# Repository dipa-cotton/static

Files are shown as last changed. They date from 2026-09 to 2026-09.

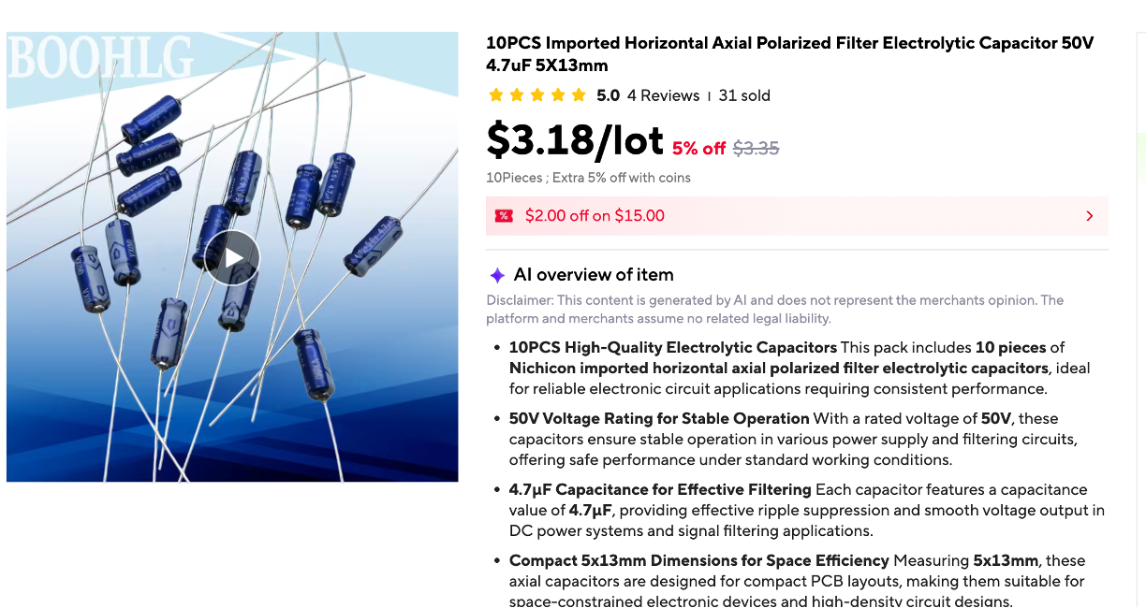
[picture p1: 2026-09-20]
production/cart image files/cart2.png

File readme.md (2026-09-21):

# static
custom FM Radio, with a SX1278 for LoRA capabilities!

## project overview
this FM radio contains a RDA5807, TDA2822, an infrared sensor, and a SX1278. these are the main components, and along with a 0.96 inch OLED display, a microSD card module, and more, this project is versatile and can both play audio as well as function as an FM radio, along with LORA capabilities.

## pictures
Screenshot 2026-09-20 at 2 40 43 PM
Screenshot 2026-09-21 at 4 08 50 PM
Screenshot 2026-09-21 at 4 09 12 PM
There was no CAD Case built for this project, so the case can be built later on once the antenna and potentiometer + button placement can be visualized. (I haven't decided on the button placement for this project yet, so I don't want to constrain placement just yet. Once it is assembled, a case will be built.)

## BOM Overview
- 3 10K ohm resistor
- 1 100 ohm resistor
- 5 polarized capacitors
- 1 4.7 µF decoupling capacitor
- 3 100nF capacitors
- 1 10nF capacitor
- 2 10pf capacitors
- 1 PJ-3200
- 1 0.96in OLED Display
- 1 MicroSD Card Module
- 2 speakers
- 2 potentiometers
- 4 push buttons
- 1 XIAO rp2040 microcontroller
- 1 RDA5807
- 1 TDA2822
- 1 TSOP38238
- 1 SX1278
- 1 32 MHz Crystal
### Overall cost: (including shipping and PCB) is $58

a more detailed list can be found in BOM.csv :)

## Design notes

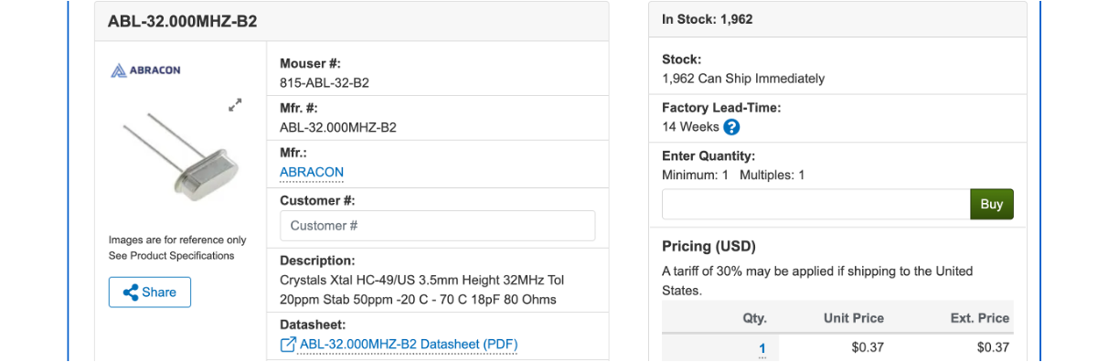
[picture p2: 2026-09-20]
production/cart image files/cart6.png

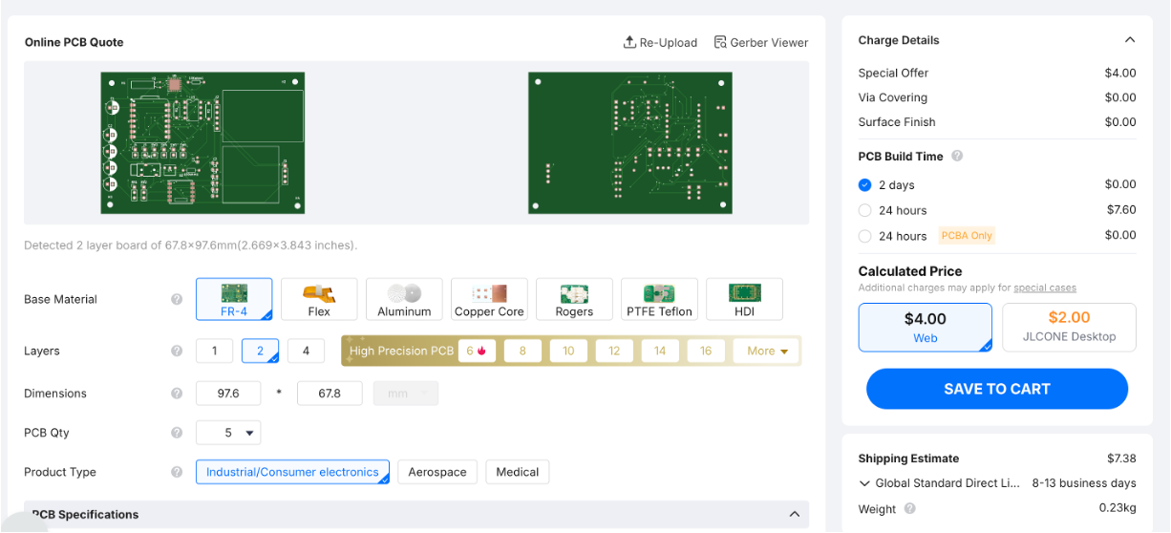
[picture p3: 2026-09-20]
production/cart image files/cart7.png

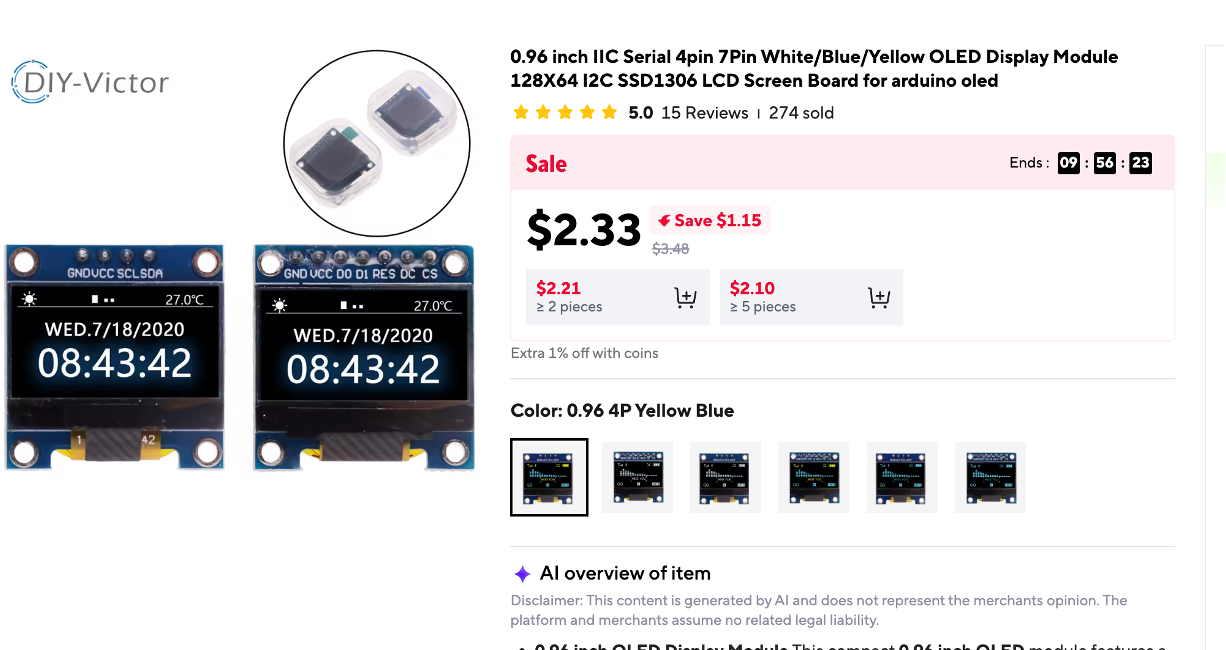
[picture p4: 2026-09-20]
production/cart image files/cart4.png

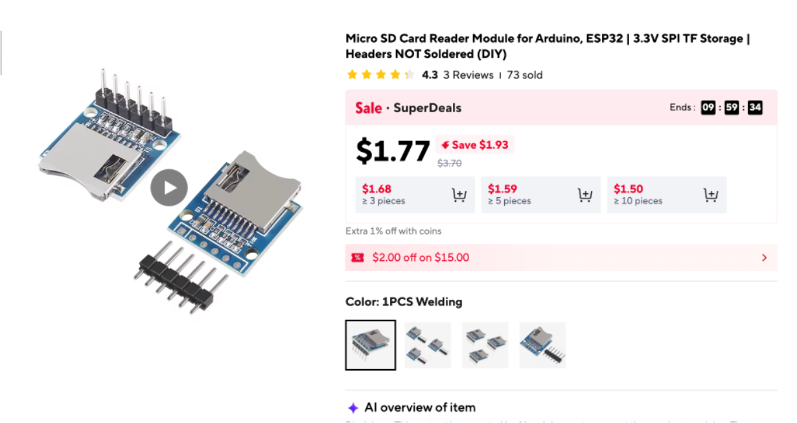
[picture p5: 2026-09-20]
production/cart image files/cart1.png

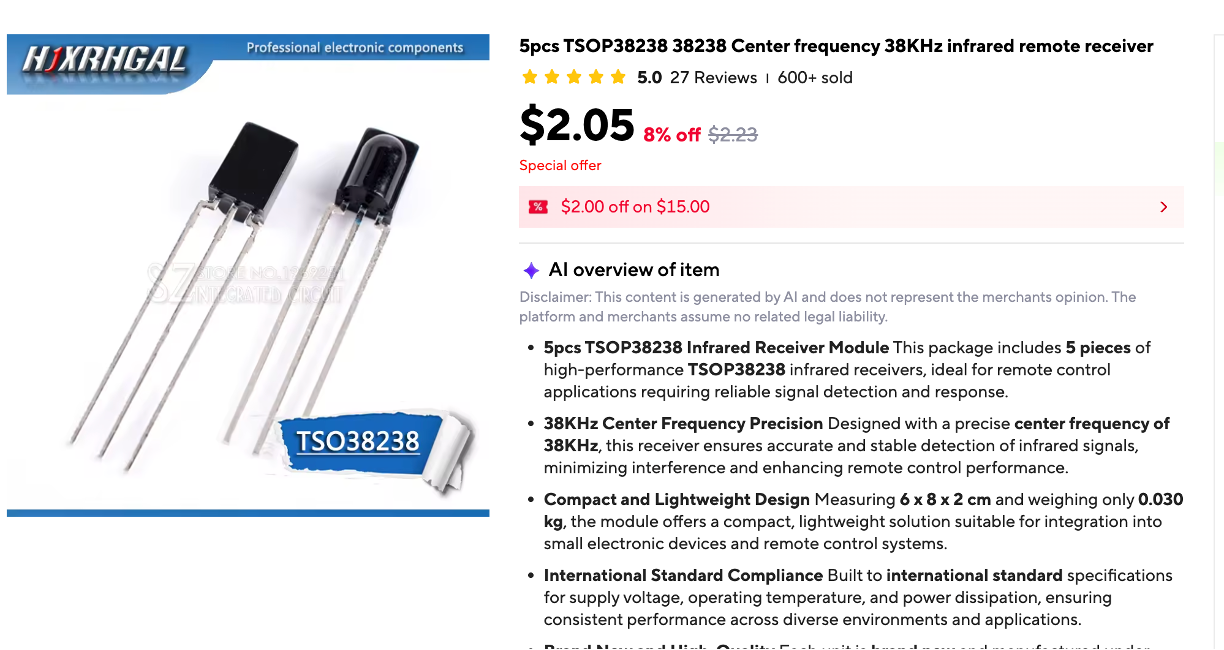
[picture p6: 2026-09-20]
production/cart image files/cart3.png

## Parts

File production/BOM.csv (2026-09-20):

Reference | Qty | Value | DNP | Footprint | Datasheet | Links to buy | Retailer | Cost (dollars)
10Kohm1,100ohm1 | 2 | R |  | Resistor_THT:R_Axial_DIN0204_L3.6mm_D1.6mm_P7.62mm_Horizontal |  | Owned | Owned | 0
C1,C2,C3,C4,C5 | 5 | C_Polarized |  | Capacitor_THT:CP_Radial_D6.3mm_P2.50mm |  | https://www.aliexpress.us/item/3256810508693915.html?curPageLogUid=OJ7CYfMdVWOt | Aliexpress | 4
C6 | 1 | 4.7µF |  | Resistor_THT:R_Axial_DIN0204_L3.6mm_D1.6mm_P1.90mm_Vertical |  | Owned | Owned | 0
C7,C8,C9 | 3 | 100nF |  | Resistor_THT:R_Axial_DIN0204_L3.6mm_D1.6mm_P1.90mm_Vertical |  | Owned | Owned | 0
C10 | 1 | 10nF |  | Resistor_THT:R_Axial_DIN0204_L3.6mm_D1.6mm_P1.90mm_Vertical |  | Owned | Owned | 0
C11,C12 | 2 | 10pf |  | Resistor_THT:R_Axial_DIN0204_L3.6mm_D1.6mm_P1.90mm_Vertical |  | Owned | Owned | 0
CN1 | 1 | PJ-3200 |  | static:AUDIO-TH_PJ-3200 | https://www.lcsc.com/datasheet/C2689690.pdf | included in kit | included in kit | 0
J1 | 1 | 0.96in OLED Display |  | Connector_PinHeader_2.54mm:PinHeader_1x04_P2.54mm_Vertical |  | https://www.aliexpress.us/item/3256806022799299.html?curPageLogUid=FwapZcyoFvRJ | Aliexpress | 3
J2 | 1 | MicroSD Card Module |  | Connector_PinHeader_2.54mm:PinHeader_1x06_P2.54mm_Vertical |  | https://www.aliexpress.us/item/2251832601364265.html?curPageLogUid=IZeHAfpDRn8G | Aliexpress | 2
J4 | 1 | Speaker 1 |  | Connector_PinHeader_2.54mm:PinHeader_1x02_P2.54mm_Vertical |  | included in kit | included in kit | 0
J5 | 1 | Speaker 2 |  | Connector_PinHeader_2.54mm:PinHeader_1x02_P2.54mm_Vertical |  | included in kit | included in kit | 0
R1,R2 | 2 | 10K |  | Resistor_THT:R_Axial_DIN0207_L6.3mm_D2.5mm_P7.62mm_Horizontal |  | Owned | Owned | 0
RV1,RV2 | 2 | R_Potentiometer |  | Connector_PinHeader_2.54mm:PinHeader_1x03_P2.54mm_Vertical |  | included in kit | included in kit | 0
SW3,SW4,SW5,SW6 | 4 | SW_Push |  | Connector_PinHeader_2.54mm:PinHeader_1x02_P2.54mm_Vertical |  | Owned | Owned | 0
U1 | 1 | XIAO-RP2040-DIP |  | static:XIAO-RP2040-DIP |  | included in kit | included in kit | 0
U2 | 1 | RDA5807MRRD-102V2.0 |  | static:RDA5807 | https://www.lcsc.com/datasheet/C9900205627.pdf | included in kit | included in kit | 0
U3 | 1 | TDA2822NBD |  | Package_DIP:DIP-8_W7.62mm | https://www.lcsc.com/datasheet/C51927337.pdf | included in kit | included in kit | 0
U4 | 1 | TSOP38238 |  | ir sensor:TSOP382 | https://www.vishay.com/doc?82491 | https://www.aliexpress.us/item/2251832763007870.html?curPageLogUid=QRFDtZ5iDDtf | Aliexpress | 5
U5 | 1 | SX1278 |  | Package_DFN_QFN:QFN-28-1EP_6x6mm_P0.65mm_EP4.8x4.8mm | https://semtech.my.salesforce.com/sfc/p/ | https://www.digikey.com/en/products/detail/semtech-corporation/SX1278IMLTRT/5226772?gclsrc=aw.ds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 | Digikey | 8
Y2 | 1 | 32 MHz Crystal |  | Crystal:Crystal_AT310_D3.0mm_L10.0mm_Horizontal |  | https://www.mouser.com/en/ProductDetail/ABRACON/ABL-32000MHZ-B2?qs=zLkLEWnxMJxB%252Bk6YRBW6NQ%3D%3D&mgh=1 | Mouser | 1
PCB | 5 |  |  |  |  |  | JLCPCB | 4
 |  |  |  |  |  |  | Shipping | 8 | JLCPCB
 |  |  |  |  |  |  |  | 7 | Aliexpress
 |  |  |  |  |  |  |  | 8 | Digikey
 |  |  |  |  |  |  |  | 8 | Mouser
 |  |  |  |  |  |  | Total Cost: | 58

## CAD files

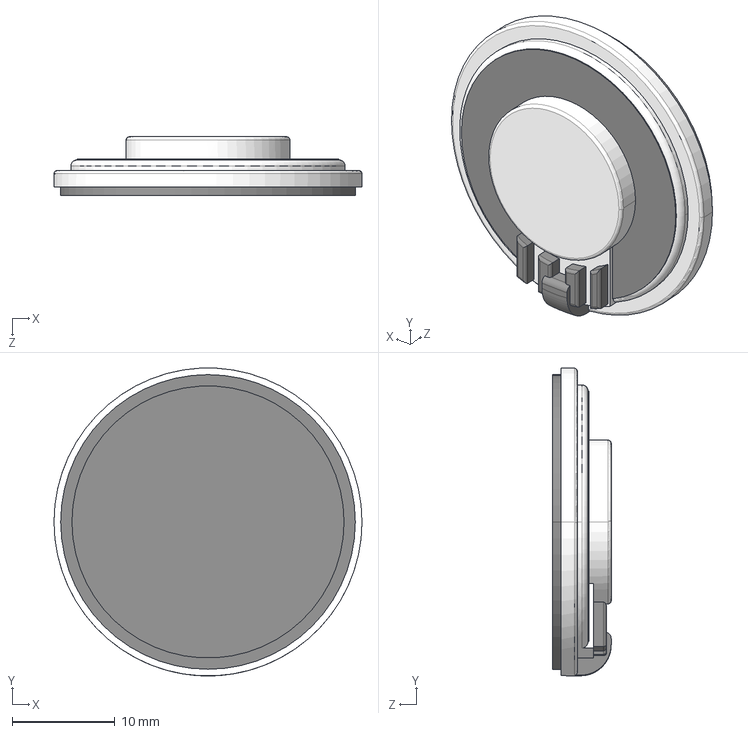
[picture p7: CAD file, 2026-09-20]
src/CAD Files/Speaker.step
30.0 x 30.0 x 5.70 mm

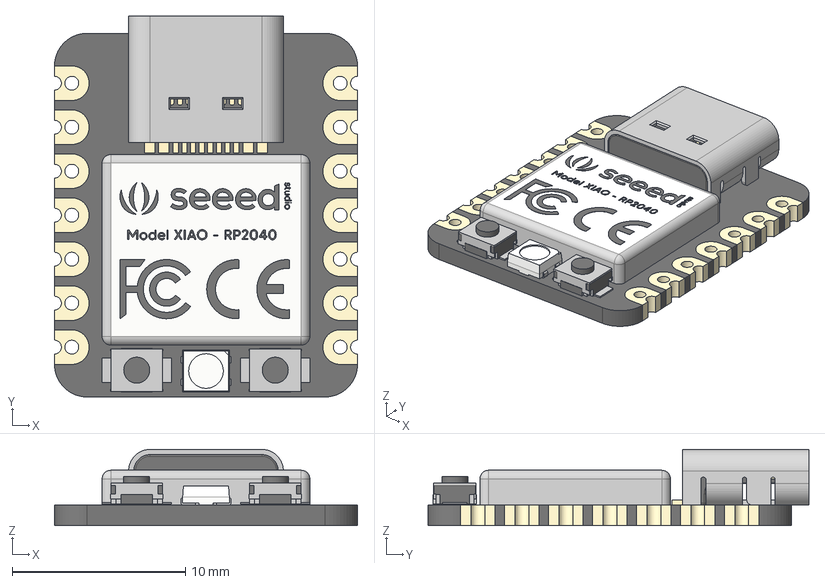
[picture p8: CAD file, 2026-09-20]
src/Static 3D Shapes/Seeed Studio XIAO RP2040 v26.step
17.5 x 22.0 x 4.40 mm
type-c v2
smd_button v3
DOUT
DIN
VSS
VDD
smd_button v3(Mirror)

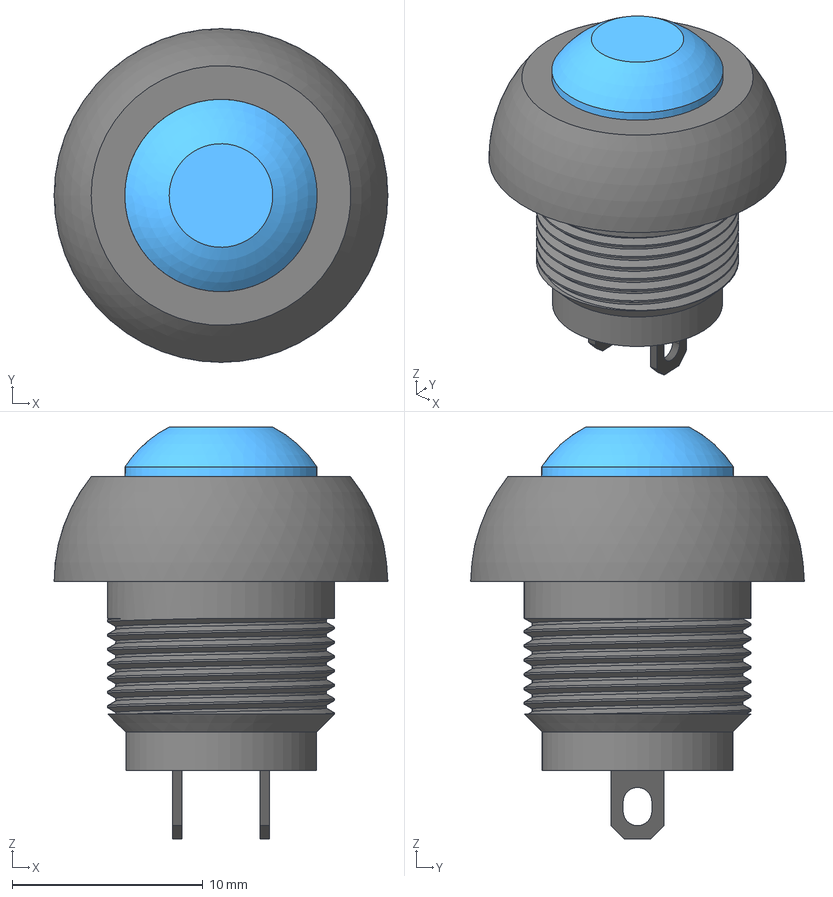
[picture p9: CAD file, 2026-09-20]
src/CAD Files/12mm Push Button.step
17.5 x 17.5 x 21.6 mm

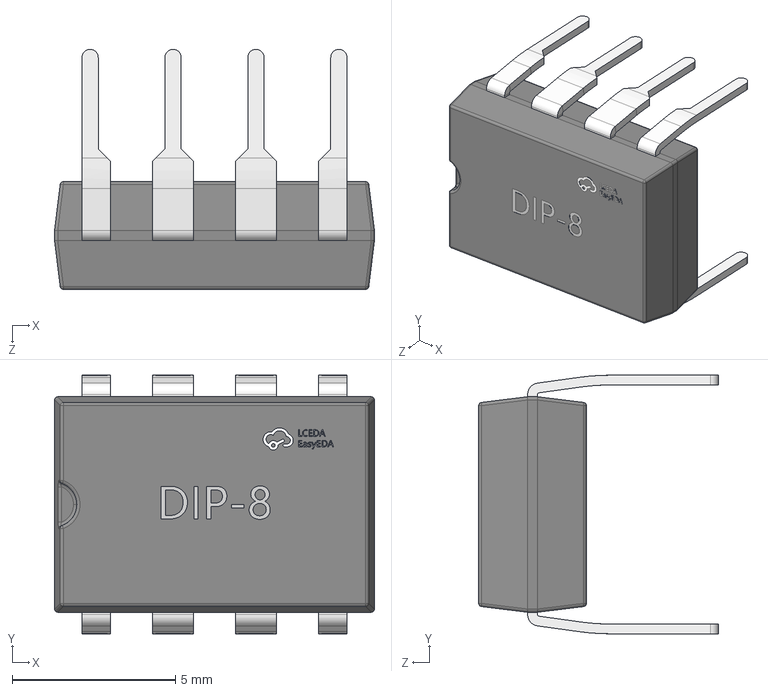
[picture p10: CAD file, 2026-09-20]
src/Static 3D Shapes/DIP-8_L9.8-W6.6-H3.5-LS7.62-P2.54.step
9.80 x 7.92 x 7.36 mm

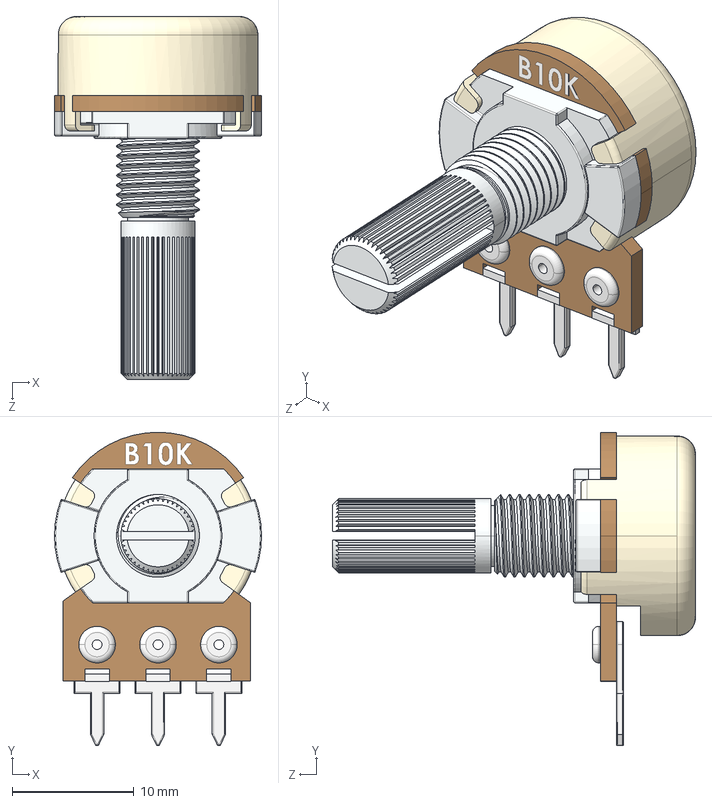
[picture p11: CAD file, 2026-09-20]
src/CAD Files/10K.STEP
17.0 x 25.7 x 29.8 mm
Peça1^Potenciometro
Peça2^Potenciometro
Peça3^Potenciometro
Peça5^Potenciometro
Peça6^Potenciometro x 3

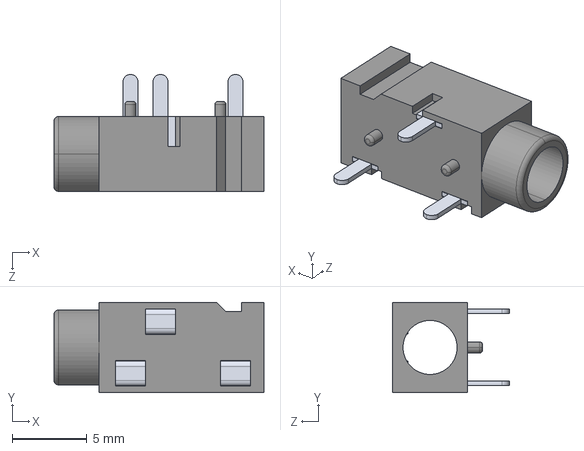
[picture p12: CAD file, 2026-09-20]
src/Static 3D Shapes/AUDIO-TH_PJ-3200.step
14.0 x 6.01 x 7.81 mm

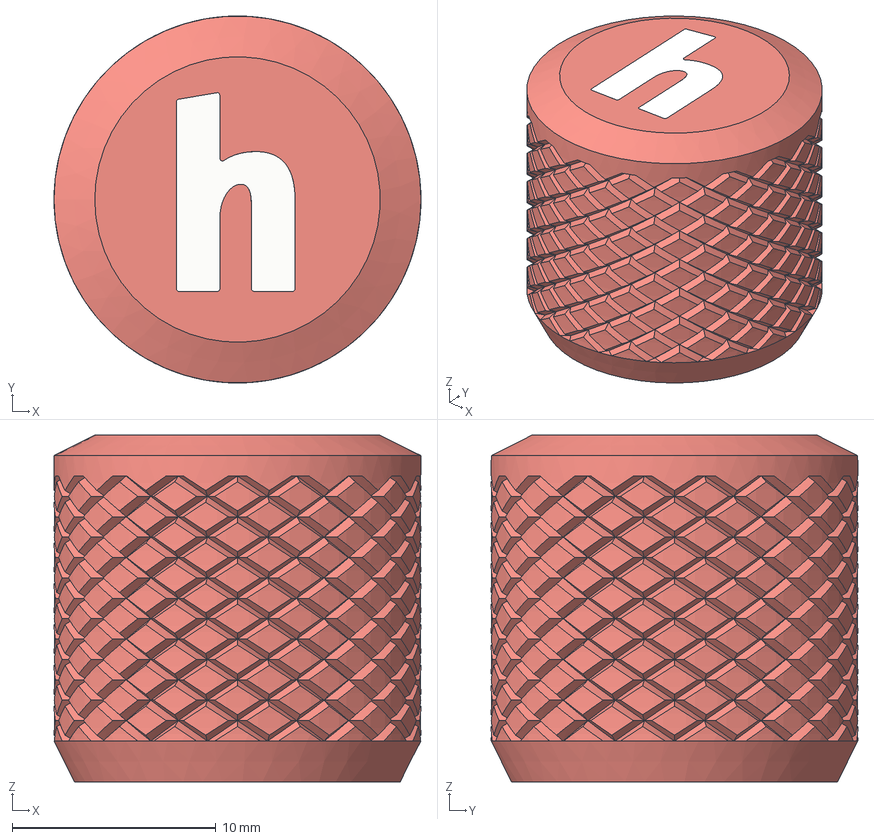
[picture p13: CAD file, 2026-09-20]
src/CAD Files/Hack Club Knurled Knob.step
18.0 x 18.0 x 17.0 mm
Base
H

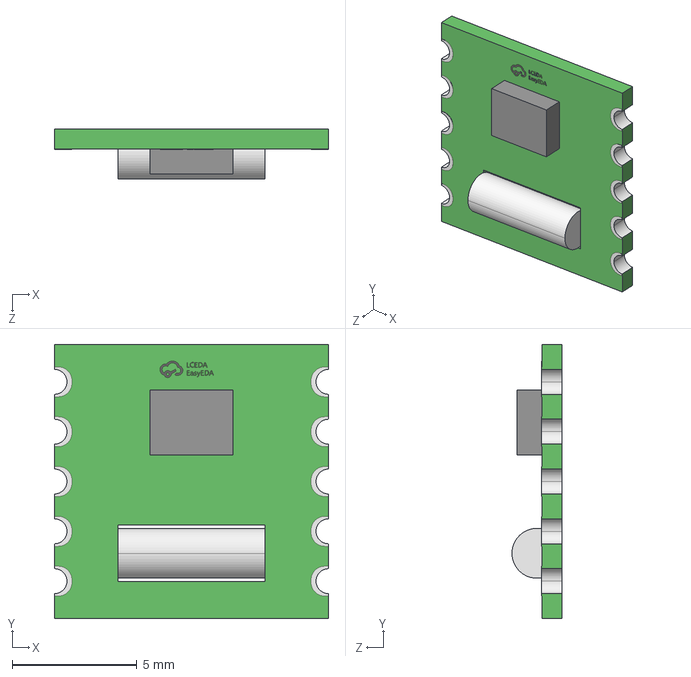
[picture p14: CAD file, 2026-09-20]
src/Static 3D Shapes/COMM-SMD_L11.0-W11.0-P2.00-TL.step
11.0 x 11.0 x 2.01 mm

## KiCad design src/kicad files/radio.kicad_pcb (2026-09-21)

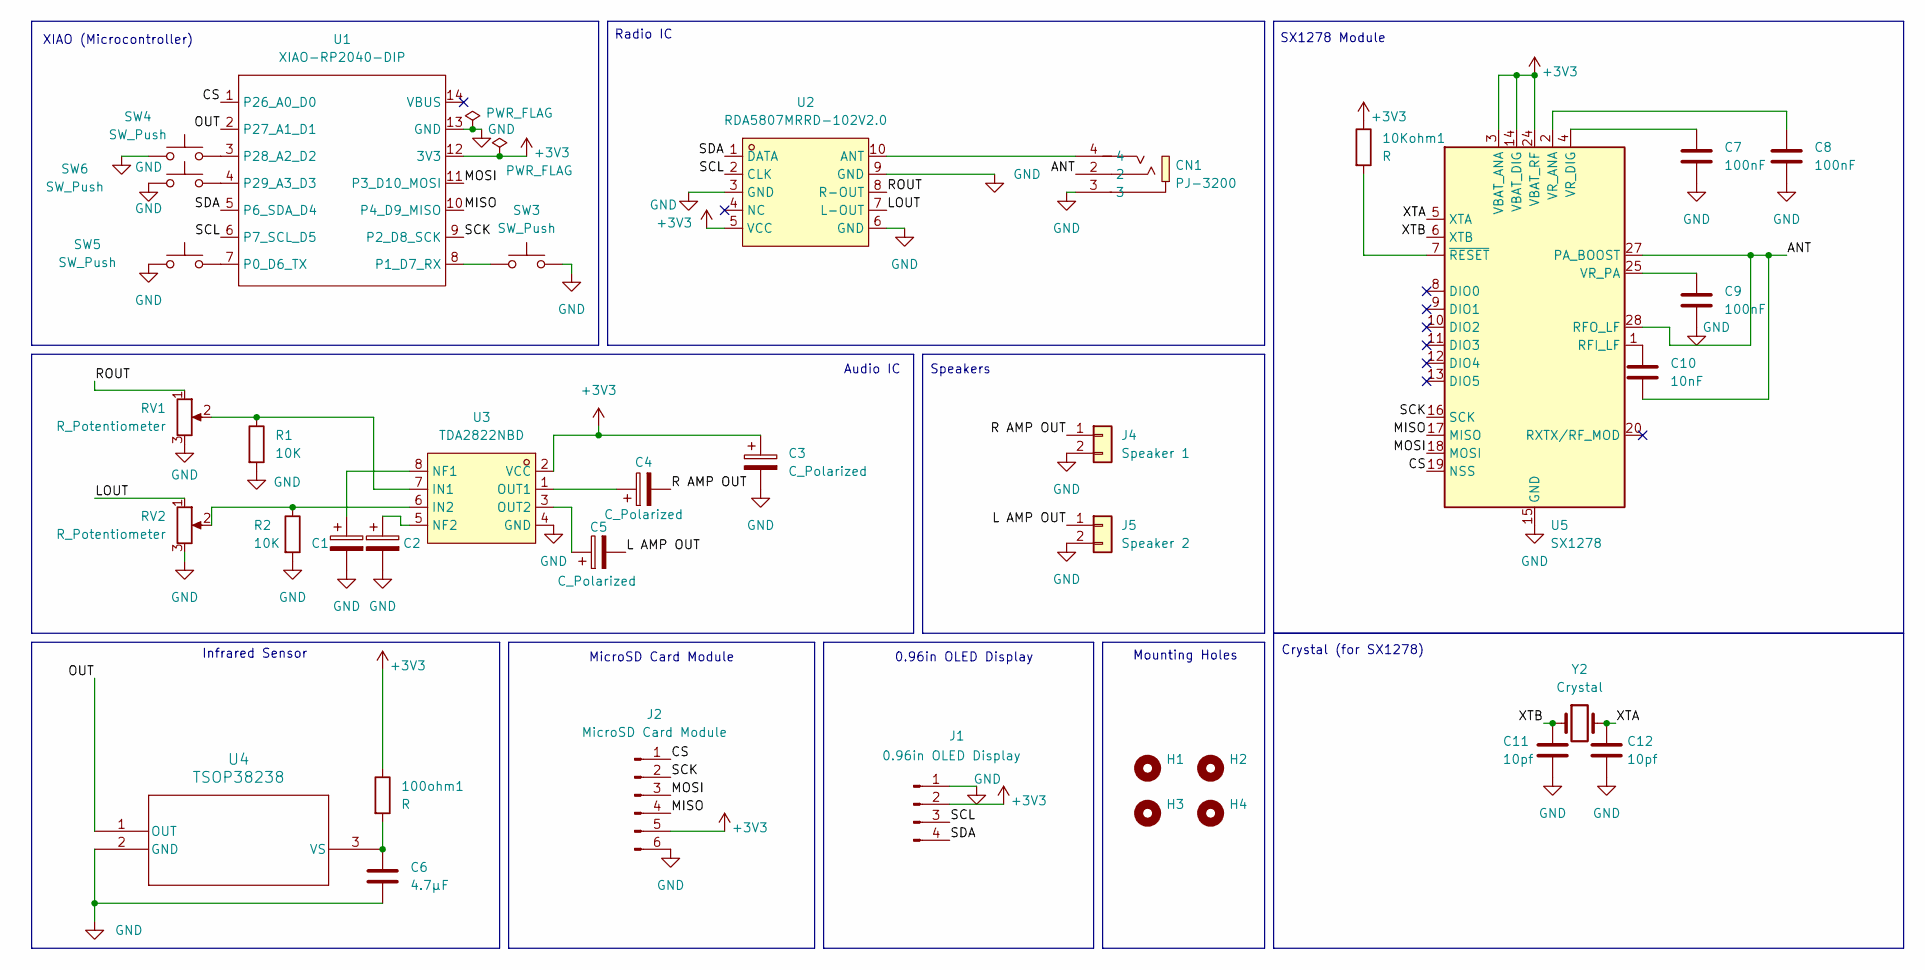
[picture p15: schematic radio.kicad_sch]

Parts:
10Kohm1, 100ohm1: R; R_Axial_DIN0204_L3.6mm_D1.6mm_P7.62mm_Horizontal
C1, C2, C3, C4, C5: C_Polarized; CP_Radial_D6.3mm_P2.50mm
C6: 4.7µF; R_Axial_DIN0204_L3.6mm_D1.6mm_P1.90mm_Vertical
C7, C8, C9: 100nF; R_Axial_DIN0204_L3.6mm_D1.6mm_P1.90mm_Vertical
C10: 10nF; R_Axial_DIN0204_L3.6mm_D1.6mm_P1.90mm_Vertical
C11, C12: 10pf; R_Axial_DIN0204_L3.6mm_D1.6mm_P1.90mm_Vertical
CN1: PJ-3200; AUDIO-TH_PJ-3200; MPN PJ-3200; LCSC Part C2689690
H1, H2, H3, H4: MountingHole; MountingHole_2.7mm_M2.5
J1: 0.96in OLED Display; PinHeader_1x04_P2.54mm_Vertical
J2: MicroSD Card Module; PinHeader_1x06_P2.54mm_Vertical
J4: Speaker 1; PinHeader_1x02_P2.54mm_Vertical
J5: Speaker 2; PinHeader_1x02_P2.54mm_Vertical
R1, R2: 10K; R_Axial_DIN0207_L6.3mm_D2.5mm_P7.62mm_Horizontal
RV1, RV2: R_Potentiometer; PinHeader_1x03_P2.54mm_Vertical
SW3, SW4, SW5, SW6: SW_Push; PinHeader_1x02_P2.54mm_Vertical
U1: XIAO-RP2040-DIP
U2: RDA5807MRRD-102V2.0; RDA5807; MPN RDA5807MRRD-102V2.0; LCSC Part C9900205627
U3: TDA2822NBD; DIP-8_W7.62mm; MPN TDA2822NBD; LCSC Part C51927337
U4: TSOP38238; TSOP382
U5: SX1278; QFN-28-1EP_6x6mm_P0.65mm_EP4.8x4.8mm
Y2: Crystal; Crystal_AT310_D3.0mm_L10.0mm_Horizontal

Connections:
+3V3: 10Kohm1.1, 100ohm1.1, C3.1, J1.2, J2.5, U1.12 (3V3), U2.5 (VCC), U3.2 (VCC), U5.3 (VBAT_ANA), U5.14 (VBAT_DIG), U5.24 (VBAT_RF)
/ANT: C10.2, CN1.2, U5.27 (PA_BOOST), U5.28 (RFO_LF)
/CS: J2.1, U1.1 (P26_A0_D0), U5.19 (NSS)
/L AMP OUT: C5.2, J5.1
/LOUT: RV2.1, U2.7 (L-OUT)
/MISO: J2.4, U1.10 (P4_D9_MISO), U5.17 (MISO)
/MOSI: J2.3, U1.11 (P3_D10_MOSI), U5.18 (MOSI)
/OUT: U1.2 (P27_A1_D1), U4.1 (OUT)
/R AMP OUT: C4.2, J4.1
/ROUT: RV1.1, U2.8 (R-OUT)
/SCK: J2.2, U1.9 (P2_D8_SCK), U5.16 (SCK)
/SCL: J1.3, U1.6 (P7_SCL_D5), U2.2 (CLK)
/SDA: J1.4, U1.5 (P6_SDA_D4), U2.1 (DATA)
/XTA: C12.1, U5.5 (XTA), Y2.2
/XTB: C11.1, U5.6 (XTB), Y2.1
GND: C1.2, C2.2, C3.2, C6.2, C7.2, C8.2, C9.2, C11.2, C12.2, CN1.3, J1.1, J2.6, J4.2, J5.2, R1.2, R2.2, RV1.3, RV2.3, SW3.2, SW4.1, SW5.1, SW6.1, U1.13 (GND), U2.3 (GND), U2.6 (GND), U2.9 (GND), U3.4 (GND), U4.2 (GND), U5.15 (GND), U5.21 (GND), U5.22 (GND), U5.23 (GND), U5.26 (GND), U5.29 (GND)
unnamed: SW5.2, U1.7 (P0_D6_TX)
unnamed: SW3.1, U1.8 (P1_D7_RX)
unnamed: SW4.2, U1.3 (P28_A2_D2)
unnamed: SW6.2, U1.4 (P29_A3_D3)
unnamed: CN1.4, U2.10 (ANT)
unnamed: R1.1, RV1.2, U3.7 (IN1)
unnamed: R2.1, RV2.2, U3.6 (IN2)
unnamed: C1.1, U3.8 (NF1)
unnamed: C2.1, U3.5 (NF2)
unnamed: C4.1, U3.1 (OUT1)
unnamed: C5.1, U3.3 (OUT2)
unnamed: 100ohm1.2, C6.1, U4.3 (VS)
unnamed: C10.1, U5.1 (RFI_LF)
unnamed: C8.1, U5.2 (VR_ANA)
unnamed: C7.1, U5.4 (VR_DIG)
unnamed: C9.1, U5.25 (VR_PA)
unnamed: 10Kohm1.2, U5.7 (~RESET)

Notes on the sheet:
MicroSD Card Module
SX1278 Module
Audio IC
Infrared Sensor
Mounting Holes
Radio IC
XIAO (Microcontroller)
Crystal (for SX1278)
0.96in OLED Display
Speakers

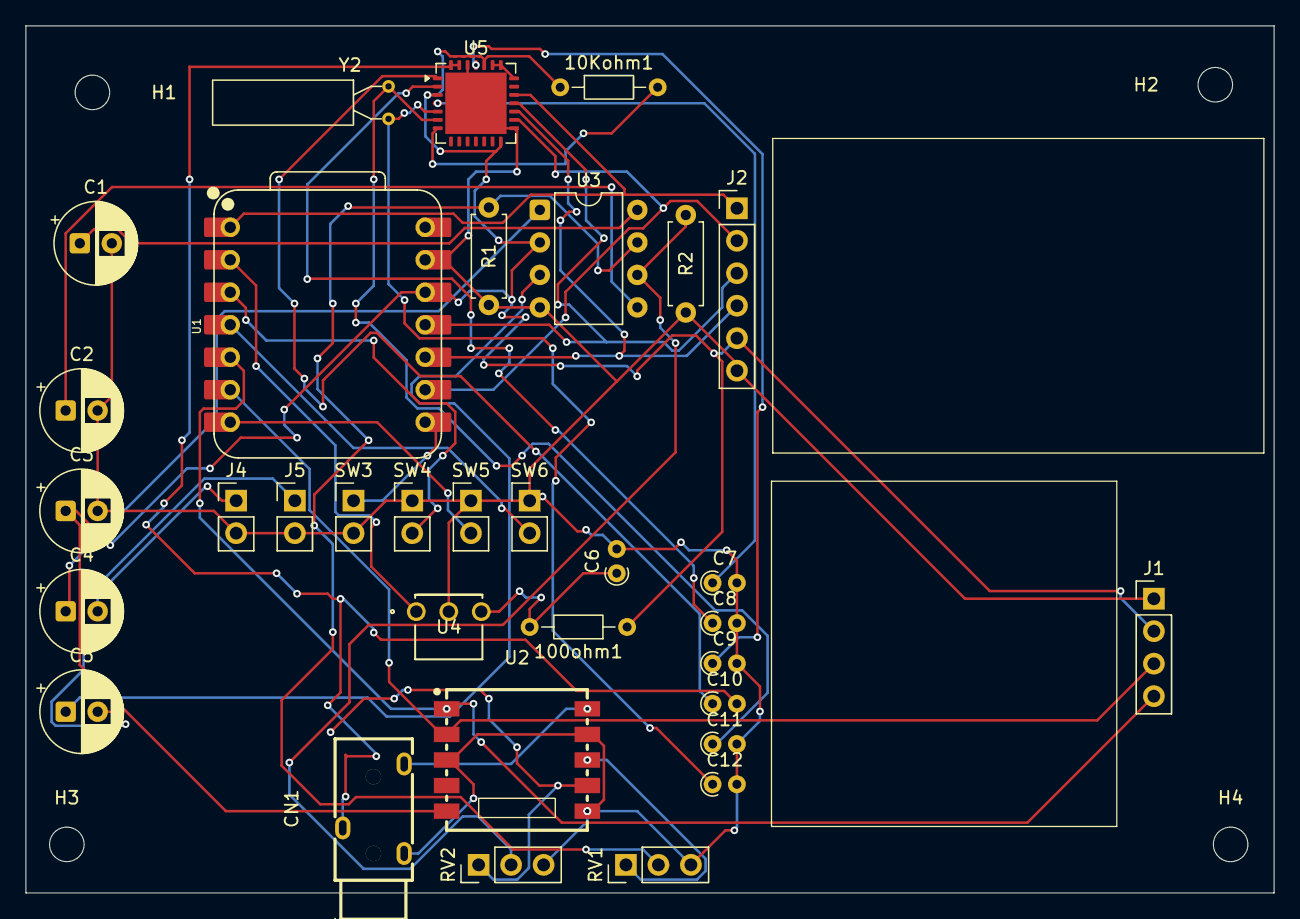
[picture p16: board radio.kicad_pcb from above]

Board: 2 copper layers, 97.6 x 67.8 mm, 37 parts (0 on the bottom side), 33 nets.

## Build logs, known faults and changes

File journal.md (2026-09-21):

# static
i'm building this radio because i want an FM radio in my room that can also play audio if i want it to. since i have a HAM radio license, i gave this radio a sx1278 chip so it can listen to more bands that i can access.

my initial idea was to just follow the guide and add an audio jack as well as a rotary encoder, but i realized that was redundant. upon reworking my project, i made multiple more adjustments, adding a microSD card holder, an OLED display, an IR sensor, and the sx1278.

## 9/15 - [Schematic]

Today I worked on my schematic.
#### Hours Spent: 2
##### What did you do?:
Today, I used KiCAD to build the schematic for the radio. Finding the footprints took me a bit!

##### Why did you do it?:
I did this to create the schematic for my project, so it can be easily manufactured ofc!

##### What problems did you face?:
I faced issues with ERC (electric rules checker), mostly unused pins lol. Other than that, not much!
Screenshot 2026-09-18 at 11 35 54 PM

## 9/16 - [PCB]
#### Hours Spent: 2
##### What did you do?:
Today, I used KiCAD to create the PCB for my project.

##### Why did you do it?:
This was done so that the radio can be manufactured!

##### What problems did you face?:
Not much, I accidentally used the wrong footprint for the XIAO at first but that was an easy fix :D

Screenshot 2026-09-18 at 11 35 43 PM
Screenshot 2026-09-18 at 11 36 10 PM

## 9/20 - [reworking]
#### Hours Spent: 5
##### What did you do?:
Today, I used KiCAD to update the schematic and pcb for this project. I also wrote the firmware and updated my github directories and files to meet the criteria for submission.

##### Why did you do it?:
This was done to make a more effective radio that aligned with my goals better, as well as meeting the submission criteria for Static. I added multiple components: a microSD card holder, an OLED display, an IR sensor, and the sx1278, as well as things like crystals and mounting holes to make the overall project much better.

##### What problems did you face?:
I faced quite a few problems, first of all, i had trouble finding the footprint and symbol for the IR sensor i wanted, but i downloaded it from this website :https://app.ultralibrarian.com/details/625a961a-107f-11e9-ab3a-0a3560a4cccc/Vishay/TSOP38238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, and was able to access it. I added it to my github as well. wiring also took much longer than last time due to the additional components, and passing the ERC and DRC was a struggle. Documenting everything also took quite a bit, with cart screenshots, a bom.csv, etc. etc.; but in the end, i'm incredibly proud of the progress i've made today and hope this can be accepted as a static submission. 
Screenshot 2026-09-20 at 2 40 43 PM
Screenshot 2026-09-20 at 2 41 09 PM
Screenshot 2026-09-20 at 2 41 28 PM
## 9/21 - [reworking]
#### Hours Spent: 1
##### What did you do?:
Today, I used KiCAD to update the pcb because i realized you couldn't plug anything in :sob:

##### Why did you do it?:
This was done to make sure my project can ACTUALLY work :D

##### What problems did you face?:
Nothing really! just deleting pcb traces and adding them back :D
Screenshot 2026-09-21 at 3 53 08 PM

#### note
There was no CAD Case built for this project, so the case can be built later on once the antenna and potentiometer + button placement can be visualized. (I haven't decided on the button placement for this project yet, so I don't want to constrain placement just yet. Once it is assembled, a case will be built.)

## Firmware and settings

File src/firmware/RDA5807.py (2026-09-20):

"""
RDA5807M FM tuner driver for CircuitPython (tested target: Seeed Xiao RP2040)

Wiring:
    RDA5807 VCC  -> 3V3
    RDA5807 GND  -> GND
    RDA5807 SDA  -> SDA
    RDA5807 SCL  -> SCL
Add 4.7k pull-ups on SDA/SCL if your breakout doesn't already have them.

Notes on the chip's I2C protocol (from the RDA5807M datasheet):
  - Fixed 7-bit address 0x10.
  - A WRITE transaction always starts at register 0x02 and auto-increments
    (0x02, 0x03, 0x04, ...). You can't address an arbitrary register directly.
  - A READ transaction always starts at register 0x0A and auto-increments
    (0x0A, 0x0B, 0x0C, ...) -- these are the status/RDS registers.
"""

import time
import board
import busio

RDA5807_ADDR = 0x10

# ---- Reg 0x02 bit positions ----
DHIZ = 1 << 15
DMUTE = 1 << 14
MONO = 1 << 13
BASS = 1 << 12
SEEKUP = 1 << 9
SEEK = 1 << 8
SKMODE = 1 << 7
NEW_METHOD = 1 << 2
SOFT_RESET = 1 << 1
ENABLE = 1 << 0

# ---- Reg 0x03 ----
TUNE = 1 << 4

BAND_87_108 = 0b00  # US/Europe
BAND_76_91 = 0b01  # Japan
BAND_76_108 = 0b10  # worldwide

SPACE_100K = 0b00
SPACE_200K = 0b01
SPACE_50K = 0b10
SPACE_25K = 0b11

_SPACE_KHZ = {SPACE_100K: 100, SPACE_200K: 200, SPACE_50K: 50, SPACE_25K: 25}
_BAND_BASE_MHZ = {BAND_87_108: 87.0, BAND_76_91: 76.0, BAND_76_108: 76.0}


class RDA5807:
    def __init__(self, i2c=None, band=BAND_87_108, space=SPACE_100K):
        self.i2c = i2c or busio.I2C(board.SCL, board.SDA, frequency=100000)
        self.band = band
        self.space = space
        self._volume = 15
        self._mono = False
        self._reg04 = 0x0200  # softmute enabled, 75us de-emphasis, AFC on
        self._init_chip()

    # ---------------- low level ----------------

    def _write_block(self, values):
        """values: list of 16-bit ints written starting at register 0x02."""
        data = bytearray(len(values) * 2)
        for i, v in enumerate(values):
            data[2 * i] = (v >> 8) & 0xFF
            data[2 * i + 1] = v & 0xFF
        while not self.i2c.try_lock():
            pass
        try:
            self.i2c.writeto(RDA5807_ADDR, bytes(data))
        finally:
            self.i2c.unlock()

    def _read_block(self, n_regs):
        """Returns a list of 16-bit ints starting at register 0x0A."""
        buf = bytearray(n_regs * 2)
        while not self.i2c.try_lock():
            pass
        try:
            self.i2c.readfrom_into(RDA5807_ADDR, buf)
        finally:
            self.i2c.unlock()
        return [(buf[2 * i] << 8) | buf[2 * i + 1] for i in range(n_regs)]

    # ---------------- setup ----------------

    def _init_chip(self):
        # Soft reset + power up first.
        self._write_block([DHIZ | ENABLE | SOFT_RESET])
        time.sleep(0.1)
        self._apply_config()
        time.sleep(0.1)

    def _apply_config(self):
        reg02 = DHIZ | ENABLE | NEW_METHOD
        if not self._mono:
            pass  # MONO bit stays 0 -> stereo
        else:
            reg02 |= MONO
        reg02 |= DMUTE  # unmute audio path

        reg03 = (self.band << 2) | self.space  # TUNE bit added per-call in tune()
        reg04 = self._reg04
        reg05 = 0x8000 | (8 << 8) | (self._volume & 0x0F)  # INT_MODE=1, default seek th, volume

        self._write_block([reg02, reg03, reg04, reg05])

    # ---------------- controls ----------------

    def set_volume(self, level):
        """0 (mute) - 15 (max)."""
        self._volume = max(0, min(15, level))
        self._apply_config()

    def set_mono(self, mono):
        self._mono = bool(mono)
        self._apply_config()

    def tune(self, freq_mhz, timeout=1.0):
        """Tune directly to a frequency in MHz."""
        base = _BAND_BASE_MHZ[self.band]
        spacing_mhz = _SPACE_KHZ[self.space] / 1000.0
        chan = int(round((freq_mhz - base) / spacing_mhz))
        chan = max(0, min(0x3FF, chan))

        reg03 = (chan << 6) | (self.band << 2) | self.space | TUNE
        # reg02 unchanged (re-send current config so it isn't reset)
        reg02 = DHIZ | ENABLE | NEW_METHOD | DMUTE | (MONO if self._mono else 0)
        self._write_block([reg02, reg03])
        self._wait_stc(timeout)

    def seek(self, up=True, timeout=3.0):
        """Seek to the next station. Returns the frequency found, or None."""
        reg02 = DHIZ | ENABLE | NEW_METHOD | DMUTE | SEEK
        if up:
            reg02 |= SEEKUP
        if self._mono:
            reg02 |= MONO
        self._write_block([reg02])
        ok = self._wait_stc(timeout)
        # Clear SEEK bit
        reg02 &= ~SEEK
        self._write_block([reg02])
        if not ok:
            return None
        status = self.read_status()
        if status["seek_fail"]:
            return None
        return status["freq_mhz"]

    def _wait_stc(self, timeout):
        start = time.monotonic()
        while time.monotonic() - start < timeout:
            status = self.read_status()
            if status["stc"]:
                return True
            time.sleep(0.02)
        return False

    def read_status(self):
        regs = self._read_block(2)  # reg 0x0A, 0x0B
        reg0a, reg0b = regs[0], regs[1]

        chan = reg0a & 0x03FF
        base = _BAND_BASE_MHZ[self.band]
        spacing_mhz = _SPACE_KHZ[self.space] / 1000.0
        freq_mhz = base + chan * spacing_mhz

        return {
            "rds_ready": bool(reg0a & (1 << 15)),
            "stc": bool(reg0a & (1 << 14)),
            "seek_fail": bool(reg0a & (1 << 13)),
            "stereo": bool(reg0a & (1 << 10)),
            "channel": chan,
            "freq_mhz": round(freq_mhz, 2),
            "rssi": (reg0b >> 9) & 0x7F,
            "fm_true": bool(reg0b & (1 << 8)),
            "fm_ready": bool(reg0b & (1 << 7)),
        }

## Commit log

2026-09-19 Create readme.md for custom FM radio project
    Added a detailed readme for the custom FM radio project, including purpose, components, pictures, BOM, and journal entries documenting the development process.
2026-09-20 fixing up the directory
    [radio-B_Cu.gbr, radio-B_Mask.gbr, radio-B_Paste.gbr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]
2026-09-20 src folder made!
    [radio.kicad_pcb, radio.kicad_sch]
2026-09-20 Update journal with project progress entries
    Added detailed journal entries for project progress including schematic and PCB design phases.
2026-09-20 symbols and footprints
2026-09-20 static stuff uploaded
    [10K.STEP, 12mm Push Button.step, AUDIO-TH_PJ-3200.step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]
2026-09-20 Revise readme with project details and BOM
    Updated project overview, components, and BOM details for clarity and completeness. Added images and additional information about the project.
2026-09-21 updated with changes
    [radio-B_Cu.gbr, radio-B_Mask.gbr, radio-B_Paste.gbr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]
